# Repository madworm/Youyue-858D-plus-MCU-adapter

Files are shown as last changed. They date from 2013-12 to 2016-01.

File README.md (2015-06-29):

Youyue-858D+ MCU-adapter:
=========================

LAYOUT FILES: ATmega168/328 adapter board for the Youyue 858D+.  

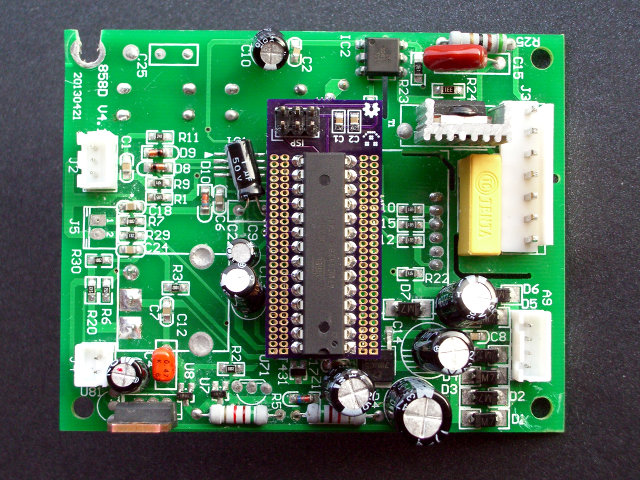
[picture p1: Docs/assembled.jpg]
Adapter front


The purpose if this little board is to add an ISP header and a convenient way of adding
more stuff via some TH solder pads.

The old MCU (ATmega8) + socket are removed and replaced with a new DIP28 socket (machined pins).
These same machined pins go into the bigger holes of the adapter board and form a
low-profile socket for the new MCU (ATmega168). The adapter board then plugs into
the socket on the main circuit board.

Firmware [repository](https://github.com/madworm/Youyue-858D-plus).

---

Safety information / disclaimer:
================================
                                                                                                                                                             
Making any modifications to this device may cause you irreversible physical harm or worse.                                                                   
You do this at your own risk.                                                                                                                                
                                                                                                                                                             
There is a significant risk of lethal electrical shock, so if you still insist of doing so, make sure to                                                     
ALWAYS UNPLUG THE MAINS CABLE before dismantling the device. Check repeatedly.                                                                               
                                                                                                                                                             
If you have an isolation transformer - do use it.

---

Before having PC-boards made, please make sure you know about your manufacturer's peculiarities!
Especially drill-sizes and their tolerances may vary too much and give you trouble.

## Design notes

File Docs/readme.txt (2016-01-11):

The big holes used for the DIP-28 chip are intended to be used for these machined
sockets (pulled out of the plastic and soldered individually).

Preferrably get the MPE/Garry types, these are guaranteed to work.

These may work, check the datasheet for dimensions:

digikey: ED90054-ND

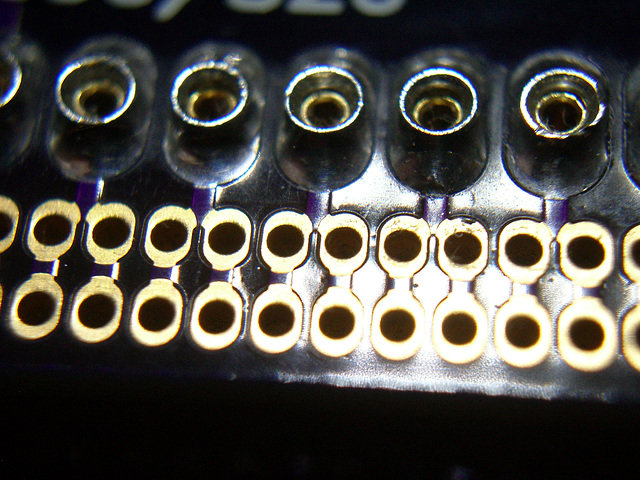
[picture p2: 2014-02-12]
Docs/IMGP8795.JPG_640.jpg

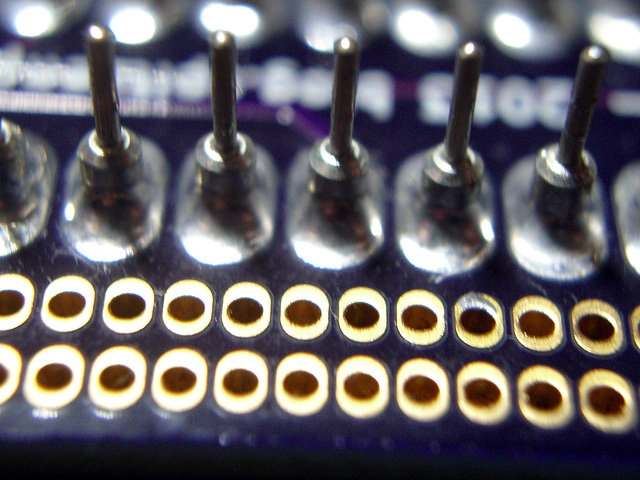
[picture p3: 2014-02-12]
Docs/IMGP8794.JPG_640.jpg

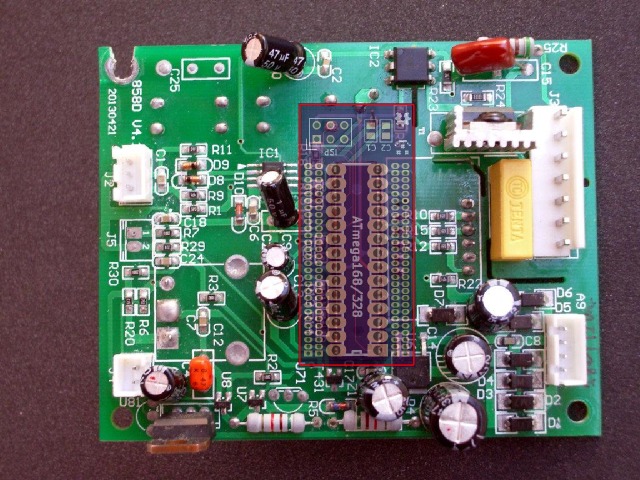
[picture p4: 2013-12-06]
Docs/mockup.jpg

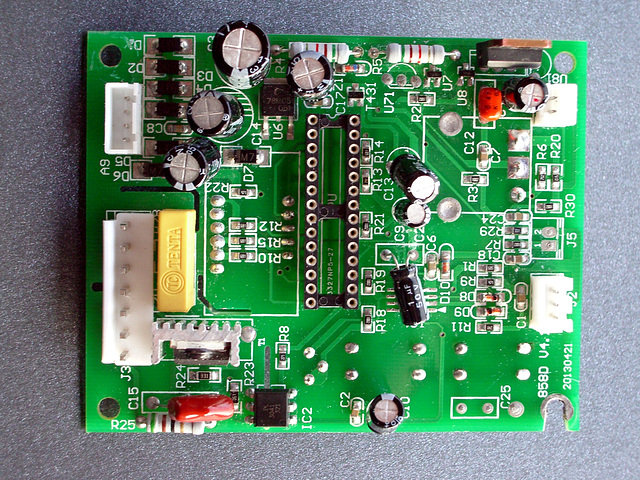
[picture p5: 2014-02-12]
Docs/IMGP8798.JPG_640.jpg

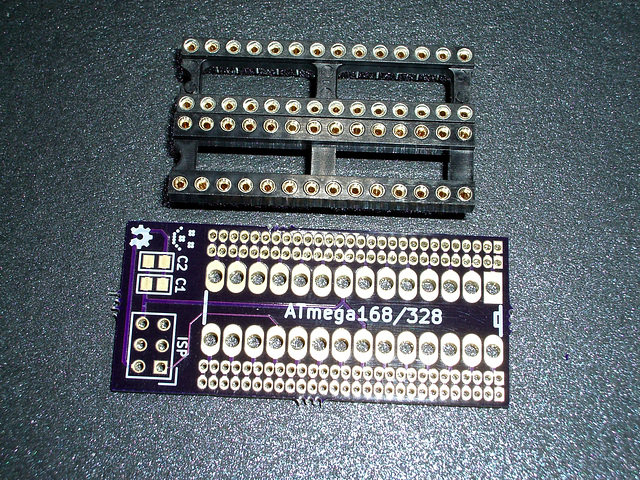
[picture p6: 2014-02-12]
Docs/IMGP8780.JPG_640.jpg

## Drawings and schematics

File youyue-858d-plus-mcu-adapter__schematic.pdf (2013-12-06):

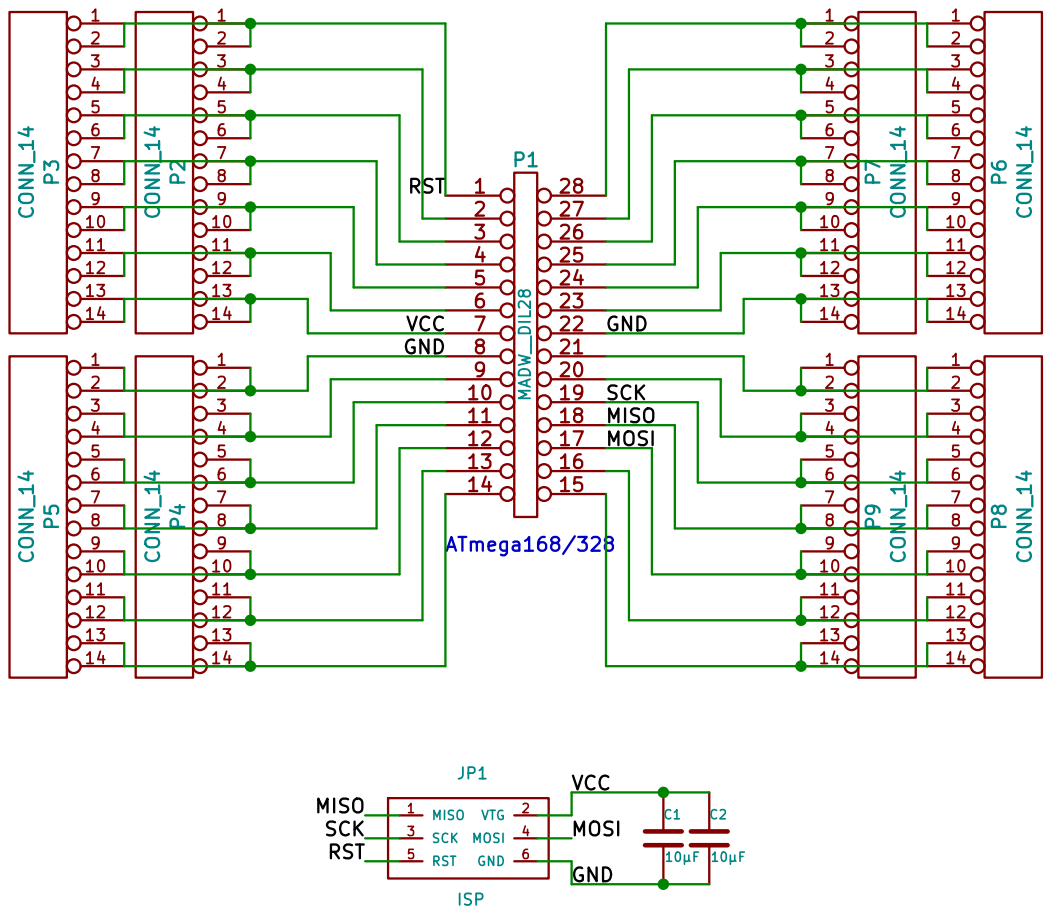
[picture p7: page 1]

File: youyue-858d-plus-mcu-adapter.sch Sheet: / 2013 - blog.spitzenpfeil.org 123456789

Id: 1/1 Title: Youyue 858D+ MCU Adapter

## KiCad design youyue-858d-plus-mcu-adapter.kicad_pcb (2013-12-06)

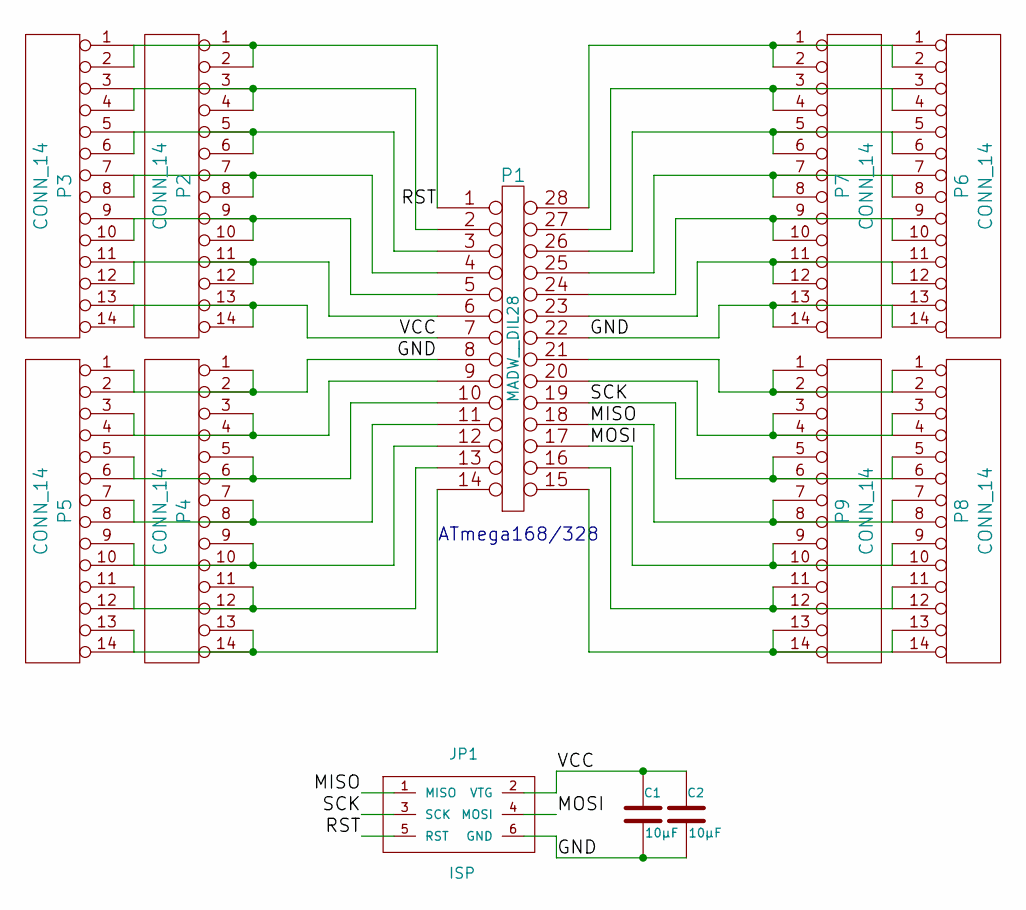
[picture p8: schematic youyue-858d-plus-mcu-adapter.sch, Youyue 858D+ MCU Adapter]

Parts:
C1, C2: 10µF
JP1: ISP
P1: MADW__DIL28
P2, P3, P4, P5, P6, P7, P8, P9: CONN_14

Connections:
/GND: C1.2, C2.2, JP1.6 (GND), P1.8, P1.22, P4.1, P4.2, P5.1, P5.2, P6.13, P6.14, P7.13, P7.14
/MISO: JP1.1 (MISO), P1.18, P8.7, P8.8, P9.7, P9.8
/MOSI: JP1.4 (MOSI), P1.17, P8.9, P8.10, P9.9, P9.10
/RST: JP1.5 (RST), P1.1, P2.1, P2.2, P3.1, P3.2
/SCK: JP1.3 (SCK), P1.19, P8.5, P8.6, P9.5, P9.6
/VCC: C1.1, C2.1, JP1.2 (VTG), P1.7, P2.13, P2.14, P3.13, P3.14
unnamed: P1.2, P2.3, P2.4, P3.3, P3.4
unnamed: P1.3, P2.5, P2.6, P3.5, P3.6
unnamed: P1.4, P2.7, P2.8, P3.7, P3.8
unnamed: P1.5, P2.9, P2.10, P3.9, P3.10
unnamed: P1.6, P2.11, P2.12, P3.11, P3.12
unnamed: P1.9, P4.3, P4.4, P5.3, P5.4
unnamed: P1.10, P4.5, P4.6, P5.5, P5.6
unnamed: P1.11, P4.7, P4.8, P5.7, P5.8
unnamed: P1.12, P4.9, P4.10, P5.9, P5.10
unnamed: P1.13, P4.11, P4.12, P5.11, P5.12
unnamed: P1.14, P4.13, P4.14, P5.13, P5.14
unnamed: P1.15, P8.13, P8.14, P9.13, P9.14
unnamed: P1.16, P8.11, P8.12, P9.11, P9.12
unnamed: P1.20, P8.3, P8.4, P9.3, P9.4
unnamed: P1.21, P8.1, P8.2, P9.1, P9.2
unnamed: P1.23, P6.11, P6.12, P7.11, P7.12
unnamed: P1.24, P6.9, P6.10, P7.9, P7.10
unnamed: P1.25, P6.7, P6.8, P7.7, P7.8
unnamed: P1.26, P6.5, P6.6, P7.5, P7.6
unnamed: P1.27, P6.3, P6.4, P7.3, P7.4
unnamed: P1.28, P6.1, P6.2, P7.1, P7.2

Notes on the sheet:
ATmega168/328

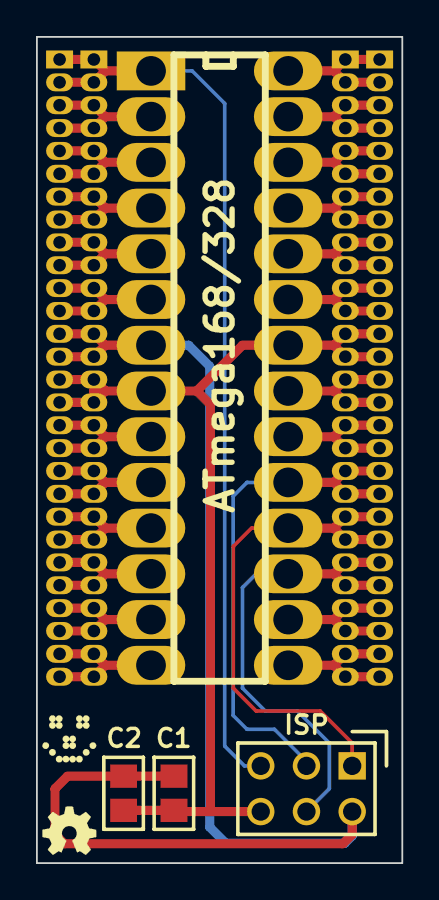
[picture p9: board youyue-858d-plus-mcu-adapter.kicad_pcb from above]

Board: 2 copper layers, 20.3 x 45.9 mm, 14 parts (0 on the bottom side), 27 nets.

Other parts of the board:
G1: OSHW-logo_silkscreen_3mm
G2: LED_smile_silkscreen_3mm

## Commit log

2013-12-06 Fixed a soldermask blunder.
    [youyue-858d-plus-mcu-adapter.kicad_pcb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]
2014-01-05 Added image of finished board to 'Docs' folder.
2014-02-12 Added a couple of illustrative images to 'Docs' folder.
2016-01-11 Renamed schematic pdf.
